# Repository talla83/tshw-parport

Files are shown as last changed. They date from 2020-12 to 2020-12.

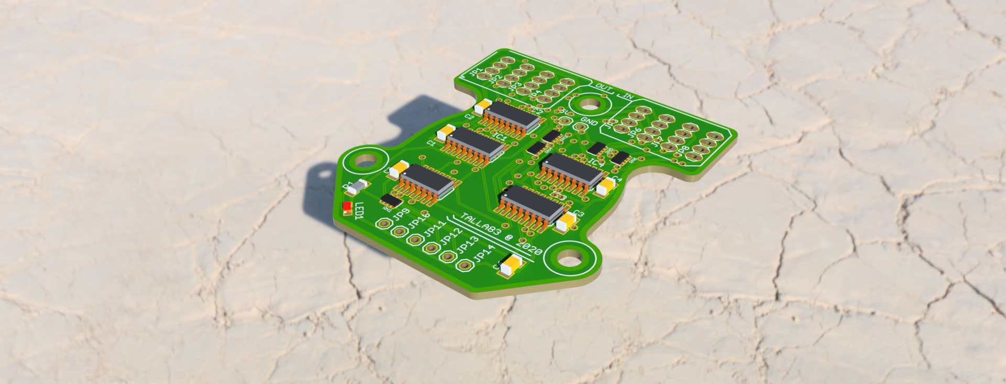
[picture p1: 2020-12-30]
Eagle/DEV_001 v9.png

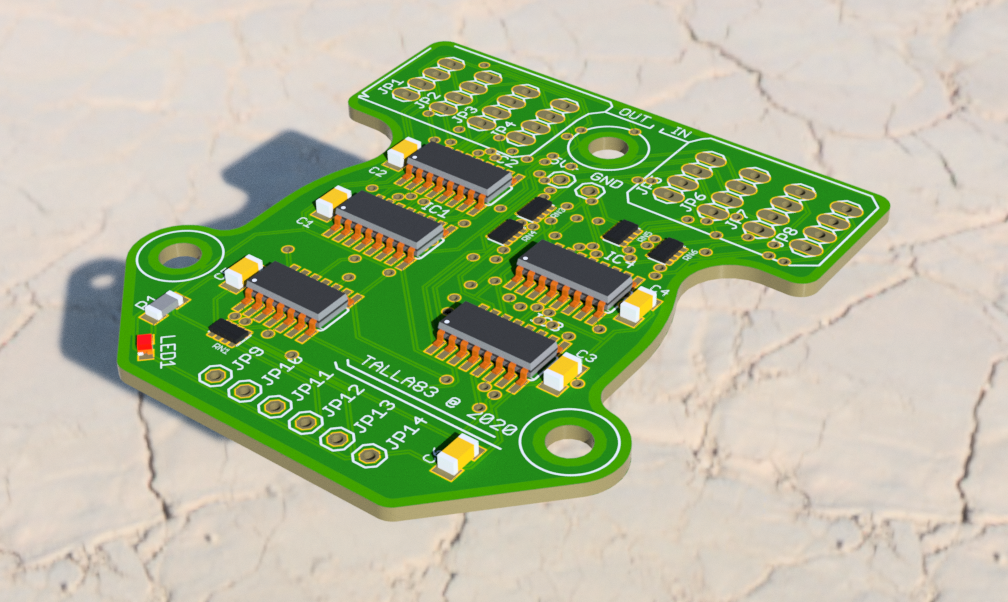
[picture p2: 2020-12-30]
Eagle/Unbenannt.PNG

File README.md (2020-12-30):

lsrio16 für Tom simple handwheel -
Eine kleine Erweiterungsplatine mit universellen IOs.

16 x digital output 16 x digital input 

Schnittstelle = Parallel Port oder andere mit GPIO

Der Encoder muss direkt an den ParPort angeschlossen.

http://wiki.linuxcnc.org/cgi-bin/wiki.pl?Shift_Register_Port_Expander

https://www.thingiverse.com/thing:3684937

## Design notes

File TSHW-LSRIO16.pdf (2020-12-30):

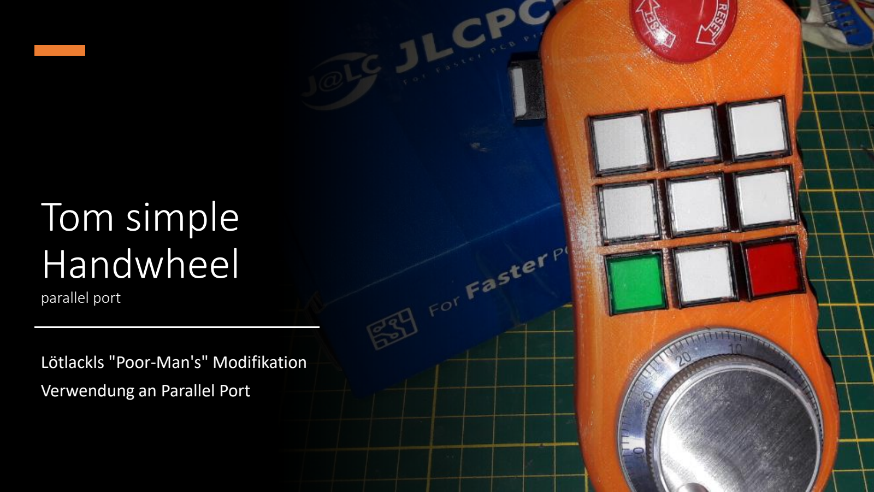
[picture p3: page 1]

# Tom simple Handwheel

parallel port

### Lötlackls "Poor-Man's" Modifikation Verwendung an Parallel Port

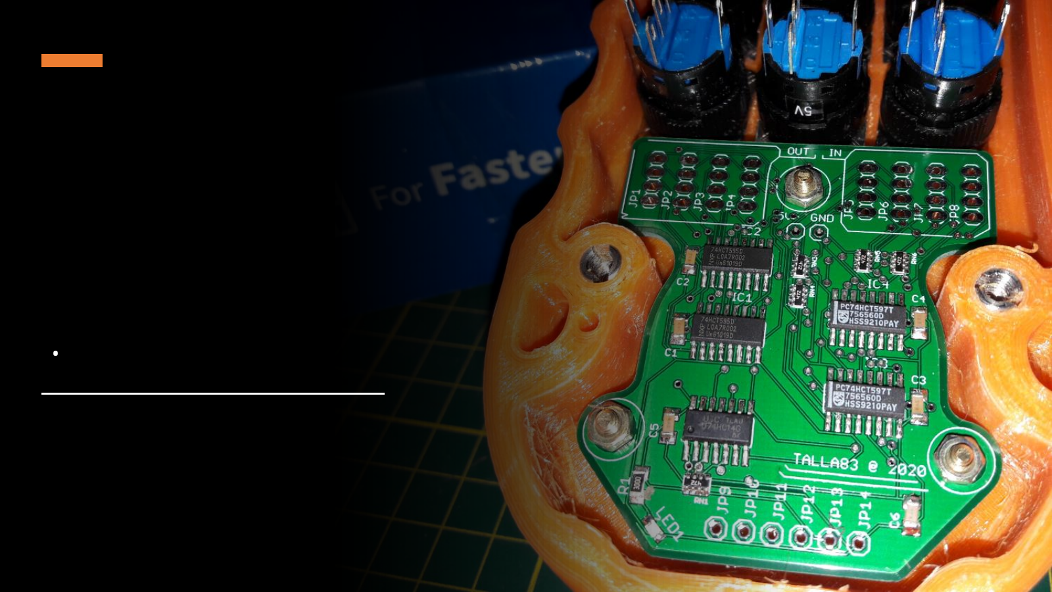
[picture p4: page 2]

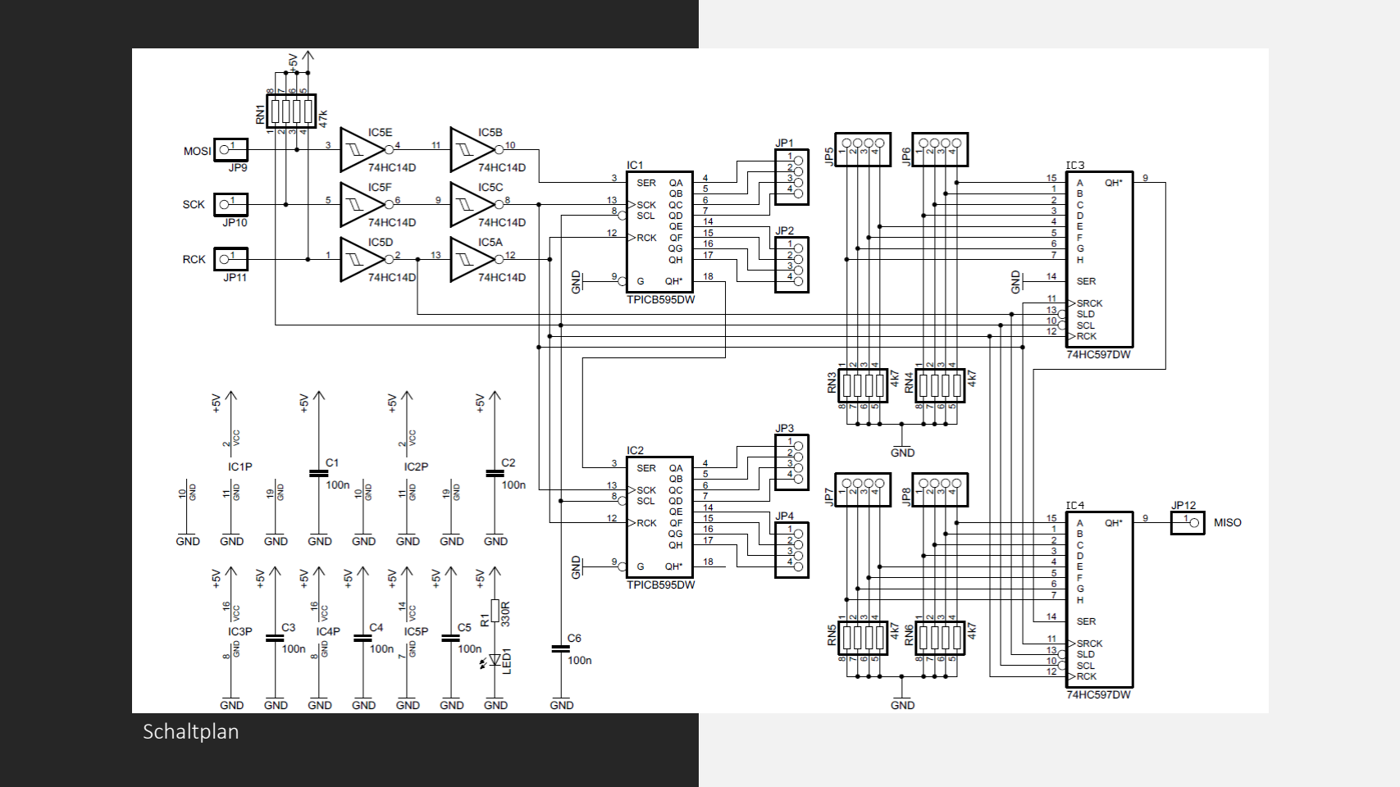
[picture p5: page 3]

Schaltplan

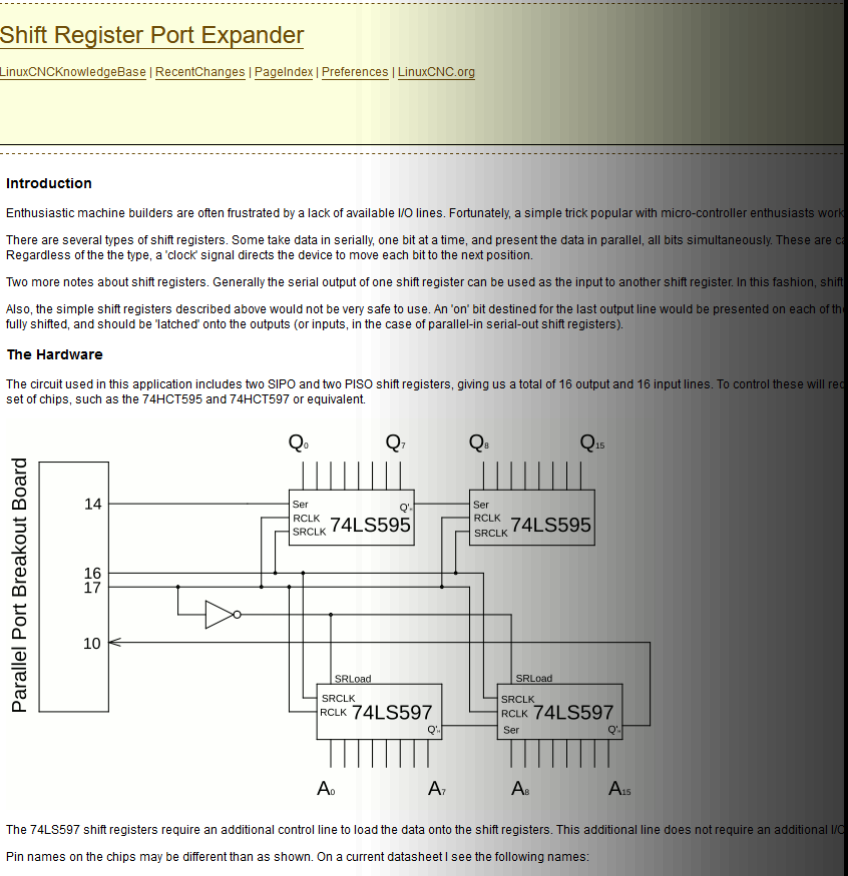
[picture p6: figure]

Die Funktionsbeschreibung gibt es hier…

http://wiki.linuxcnc.org/cgi-bin/wiki.pl?Shift_Register_Port_Expander

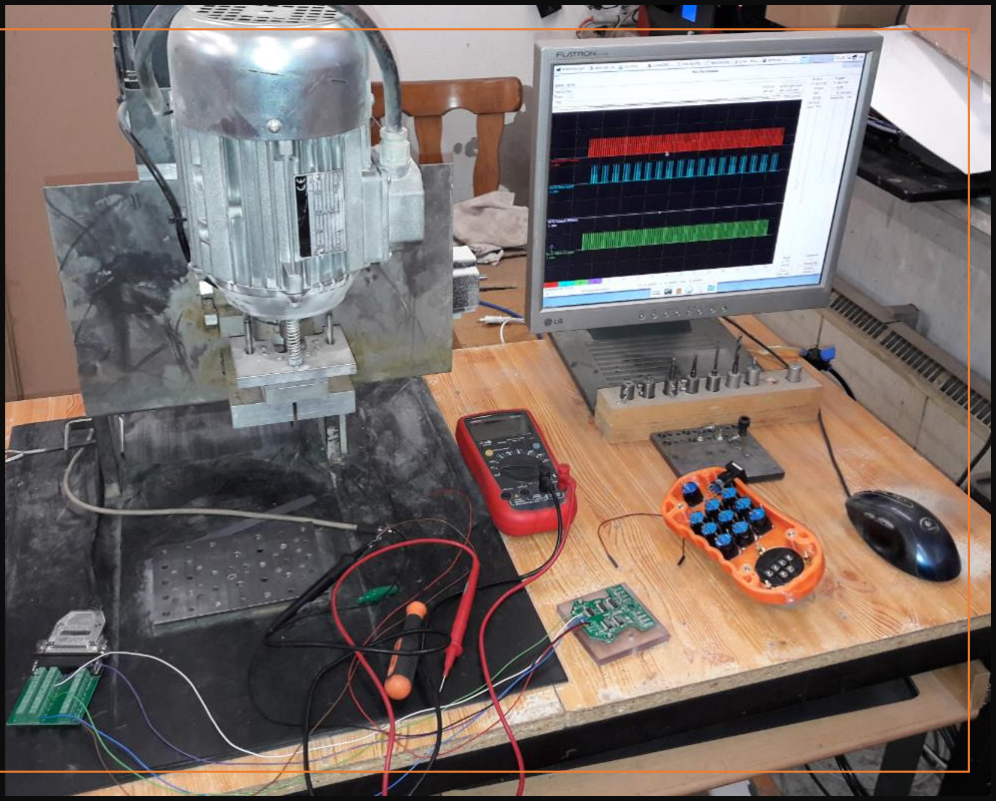
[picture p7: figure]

# Testaufbau

# Übersicht Verdrahtung

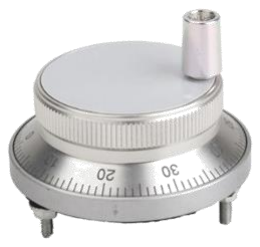
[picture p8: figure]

16 Eingänge
16 Ausgänge

Parallel Port

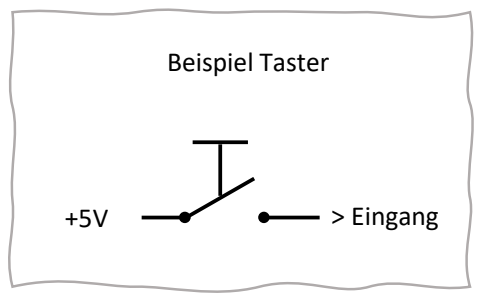
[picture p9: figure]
> Eingang; Beispiel Taster
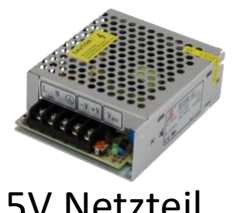
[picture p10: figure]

5V Netzteil

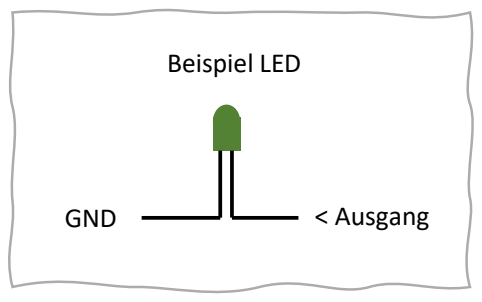
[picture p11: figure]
GND; < Ausgang; Beispiel LED

Platine | Handrad Encoder

+5V

GND

A
B

Es werden hier insgesamt 6 PINS benötigt. 3 Eingänge
3 Ausgänge

# .. lsrio16

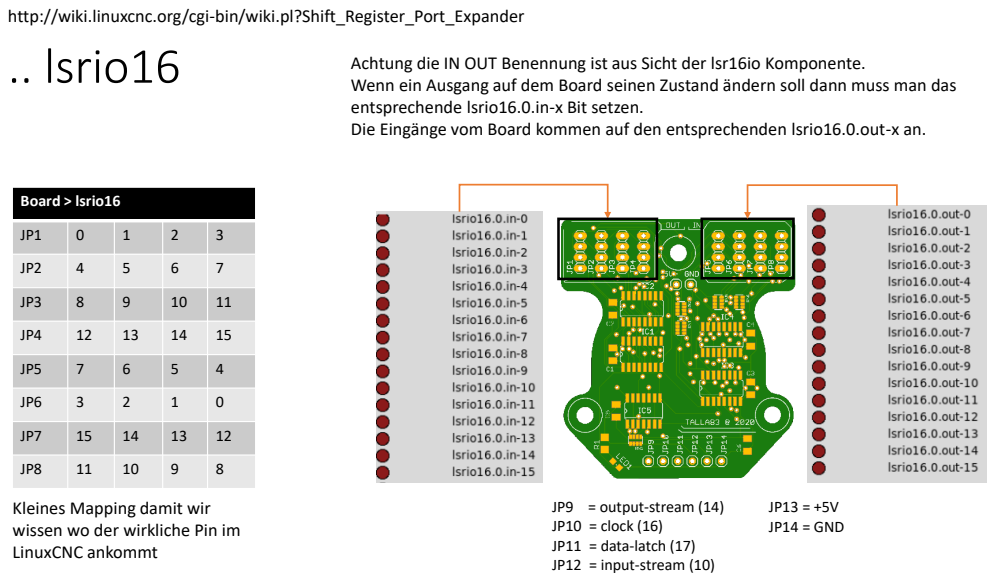
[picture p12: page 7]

http://wiki.linuxcnc.org/cgi-bin/wiki.pl?Shift_Register_Port_Expander

Achtung die IN OUT Benennung ist aus Sicht der lsr16io Komponente.
Wenn ein Ausgang auf dem Board seinen Zustand ändern soll dann muss man das
entsprechende lsrio16.0.in-x Bit setzen.
Die Eingänge vom Board kommen auf den entsprechenden lsrio16.0.out-x an.

Kleines Mapping damit wir
wissen wo der wirkliche Pin im
LinuxCNC ankommt

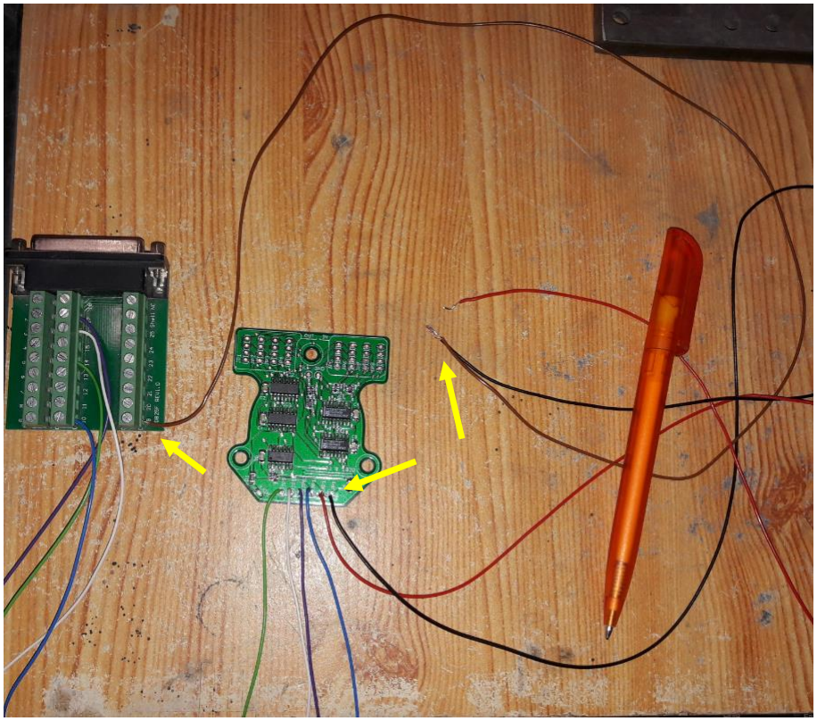
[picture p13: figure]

# .. lsrio16

GND der Spannungsversorgung muss auch mit dem GND des
Parallel Port verbunden werden!

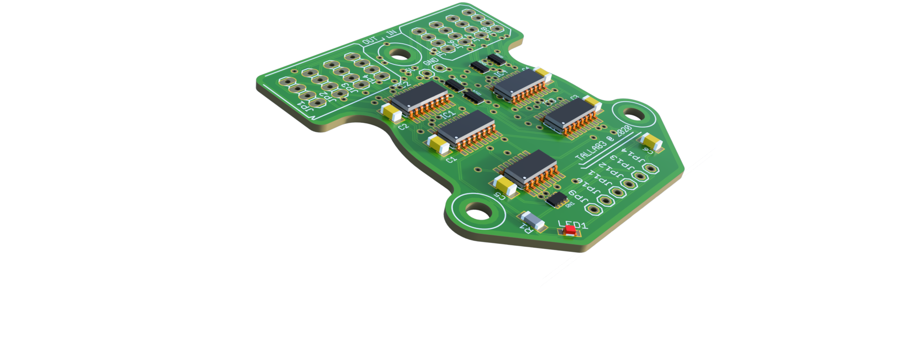
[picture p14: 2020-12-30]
Eagle/DEV_001_2020-Dec-01_08-29-42PM-000_CustomizedView25017234391.png

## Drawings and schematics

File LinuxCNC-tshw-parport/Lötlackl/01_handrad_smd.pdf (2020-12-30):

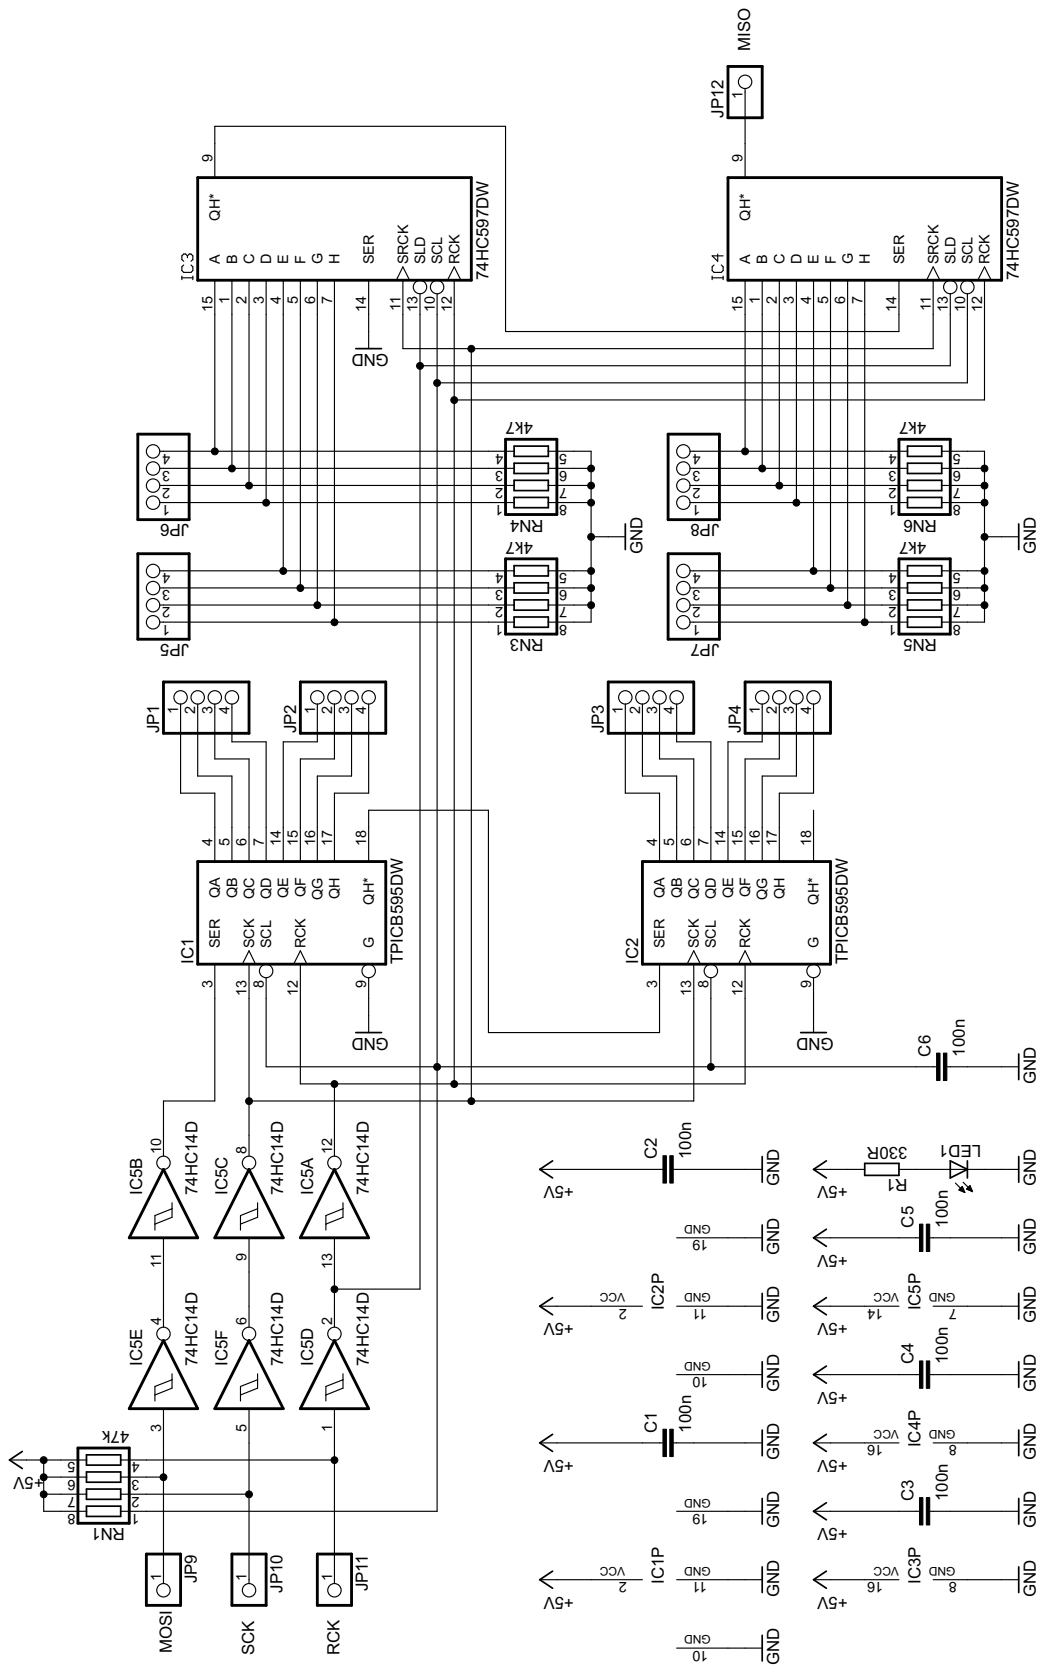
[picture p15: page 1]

GND GND

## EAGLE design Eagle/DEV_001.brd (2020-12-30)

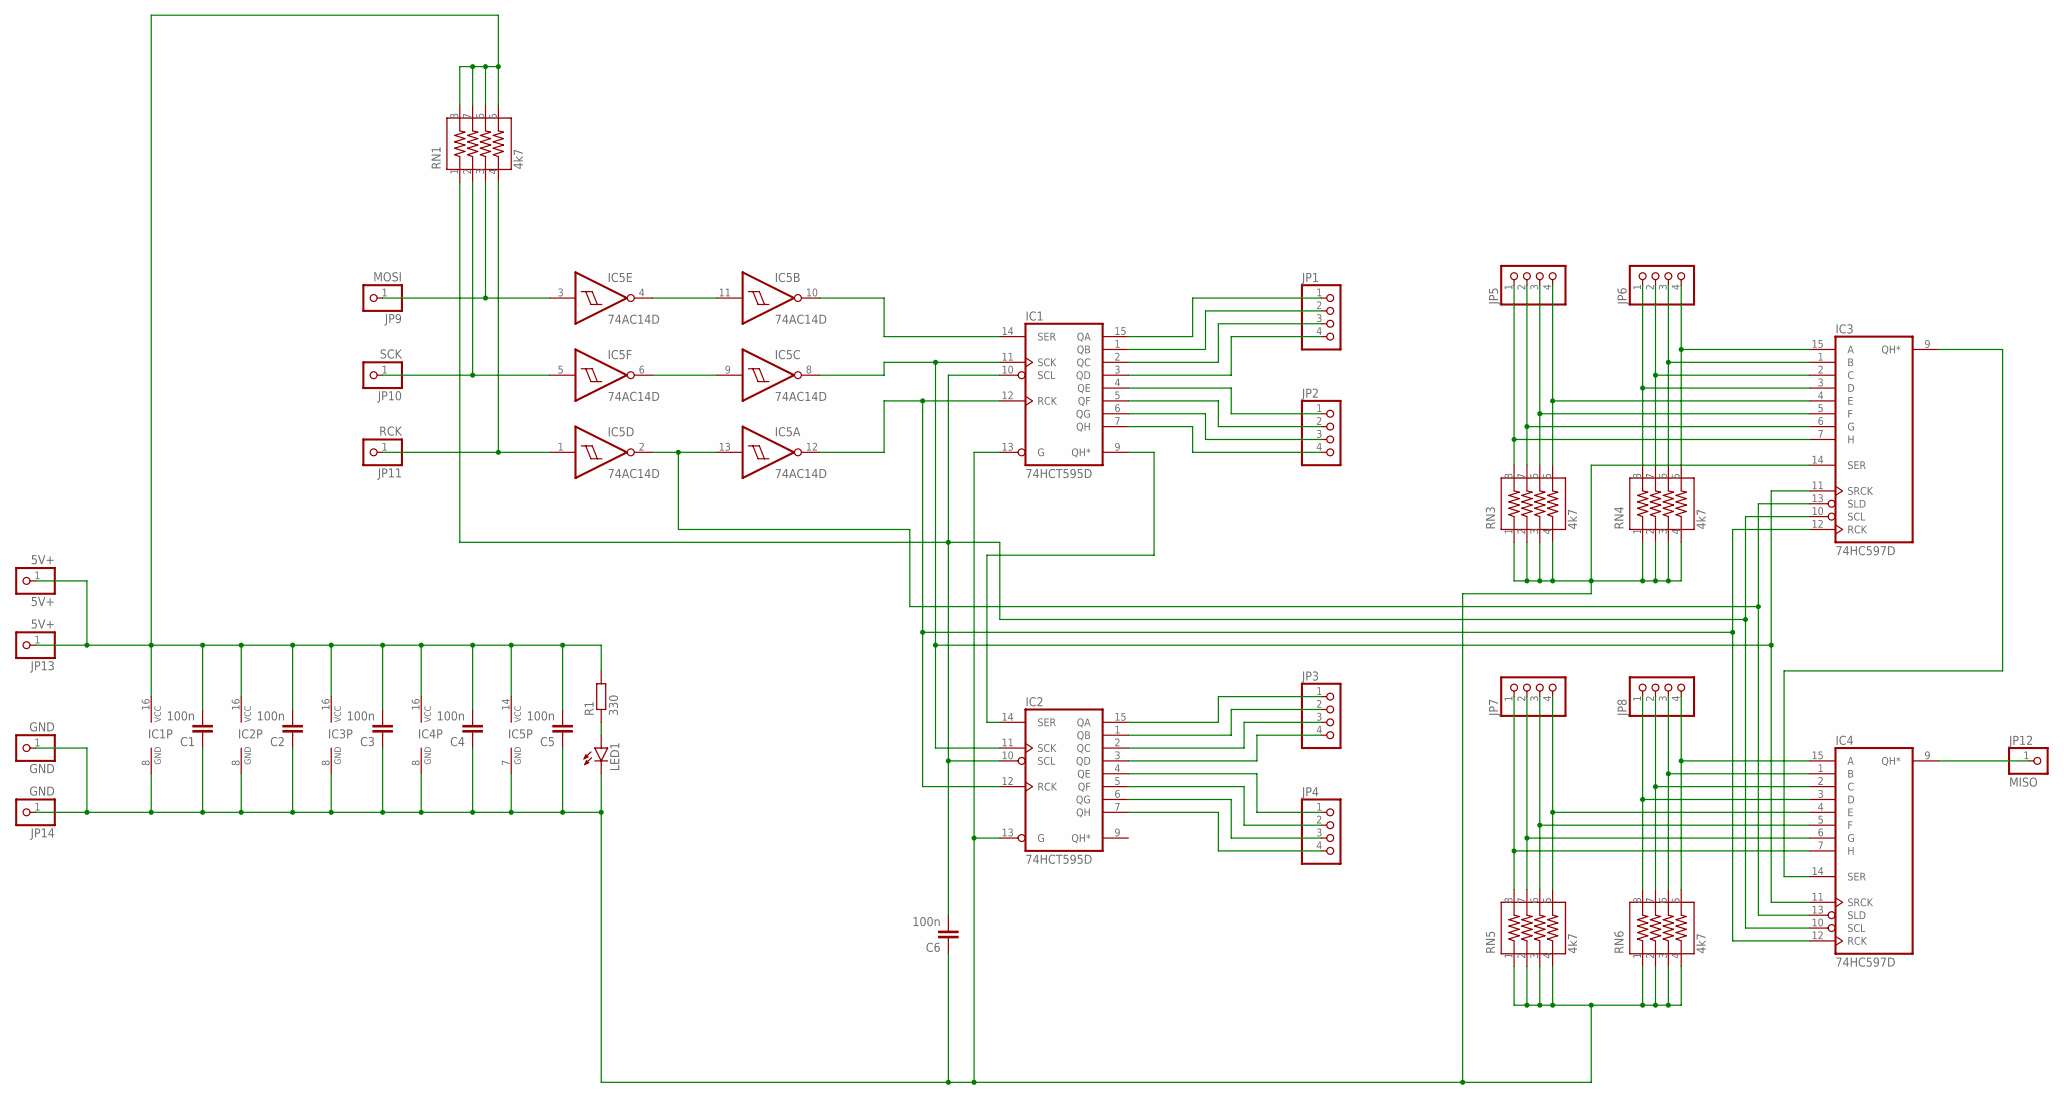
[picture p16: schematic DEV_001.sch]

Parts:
5V+: 5V+; 1X01
C1, C2, C3, C4, C5, C6: 100n; C1206K
GND: GND; 1X01
IC1, IC2: 74HCT595D; SO16
IC3, IC4: 74HC597D; SO16
IC5: 74AC14D; SO14
JP1, JP2, JP3, JP4, JP5, JP6, JP7, JP8: PINHD-1X4; 1X04
JP9: MOSI; 1X01
JP10: SCK; 1X01
JP11: RCK; 1X01
JP12: MISO; 1X01
JP13: 5V+; 1X01
JP14: GND; 1X01
LED1: LEDCHIPLED_0805; CHIPLED_0805
R1: 330; R1206
RN1, RN3, RN4, RN5, RN6: 4k7; 742C083103JP

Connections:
unnamed: IC5.4 (O), IC5.11 (I)
unnamed: IC5.6 (O), IC5.9 (I)
unnamed: IC5.3 (I), JP9.1, RN1.3
unnamed: IC5.5 (I), JP10.1, RN1.2
unnamed: IC5.1 (I), JP11.1, RN1.4
unnamed: 5V+.1, C1.2, C2.2, C3.2, C4.2, C5.2, IC1.16 (VCC), IC2.16 (VCC), IC3.16 (VCC), IC4.16 (VCC), IC5.14 (VCC), JP13.1, R1.2, RN1.5, RN1.6, RN1.7, RN1.8
unnamed: IC1.14 (SER), IC5.10 (O)
unnamed: C1.1, C2.1, C3.1, C4.1, C5.1, C6.1, GND.1, IC1.8 (GND), IC1.13 (G), IC2.8 (GND), IC2.13 (G), IC3.8 (GND), IC3.14 (SER), IC4.8 (GND), IC5.7 (GND), JP14.1, LED1.C, RN3.1, RN3.2, RN3.3, RN3.4, RN4.1, RN4.2, RN4.3, RN4.4, RN5.1, RN5.2, RN5.3, RN5.4, RN6.1, RN6.2, RN6.3, RN6.4
unnamed: IC1.15 (QA), JP1.1
unnamed: IC1.1 (QB), JP1.2
unnamed: IC1.2 (QC), JP1.3
unnamed: IC1.3 (QD), JP1.4
unnamed: IC1.4 (QE), JP2.1
unnamed: IC1.5 (QF), JP2.2
unnamed: IC1.6 (QG), JP2.3
unnamed: IC1.7 (QH), JP2.4
unnamed: IC1.9 (QH*), IC2.14 (SER)
unnamed: IC2.15 (QA), JP3.1
unnamed: IC2.1 (QB), JP3.2
unnamed: IC2.2 (QC), JP3.3
unnamed: IC2.3 (QD), JP3.4
unnamed: IC2.4 (QE), JP4.1
unnamed: IC2.5 (QF), JP4.2
unnamed: IC2.6 (QG), JP4.3
unnamed: IC2.7 (QH), JP4.4
unnamed: IC3.9 (QH*), IC4.14 (SER)
unnamed: IC4.9 (QH*), JP12.1
unnamed: IC3.7 (H), JP5.1, RN3.8
unnamed: IC3.6 (G), JP5.2, RN3.7
unnamed: IC3.5 (F), JP5.3, RN3.6
unnamed: IC3.4 (E), JP5.4, RN3.5
unnamed: IC3.3 (D), JP6.1, RN4.8
unnamed: IC3.2 (C), JP6.2, RN4.7
unnamed: IC3.1 (B), JP6.3, RN4.6
unnamed: IC3.15 (A), JP6.4, RN4.5
unnamed: IC1.11 (SCK), IC2.11 (SCK), IC3.11 (SRCK), IC4.11 (SRCK), IC5.8 (O)
unnamed: IC3.13 (SLD), IC4.13 (SLD), IC5.2 (O), IC5.13 (I)
unnamed: IC1.12 (RCK), IC2.12 (RCK), IC3.12 (RCK), IC4.12 (RCK), IC5.12 (O)
unnamed: IC4.7 (H), JP7.1, RN5.8
unnamed: IC4.6 (G), JP7.2, RN5.7
unnamed: IC4.5 (F), JP7.3, RN5.6
unnamed: IC4.4 (E), JP7.4, RN5.5
unnamed: IC4.3 (D), JP8.1, RN6.8
unnamed: IC4.2 (C), JP8.2, RN6.7
unnamed: IC4.1 (B), JP8.3, RN6.6
unnamed: IC4.15 (A), JP8.4, RN6.5
unnamed: LED1.A, R1.1
unnamed: C6.2, IC1.10 (SCL), IC2.10 (SCL), IC3.10 (SCL), IC4.10 (SCL), RN1.1

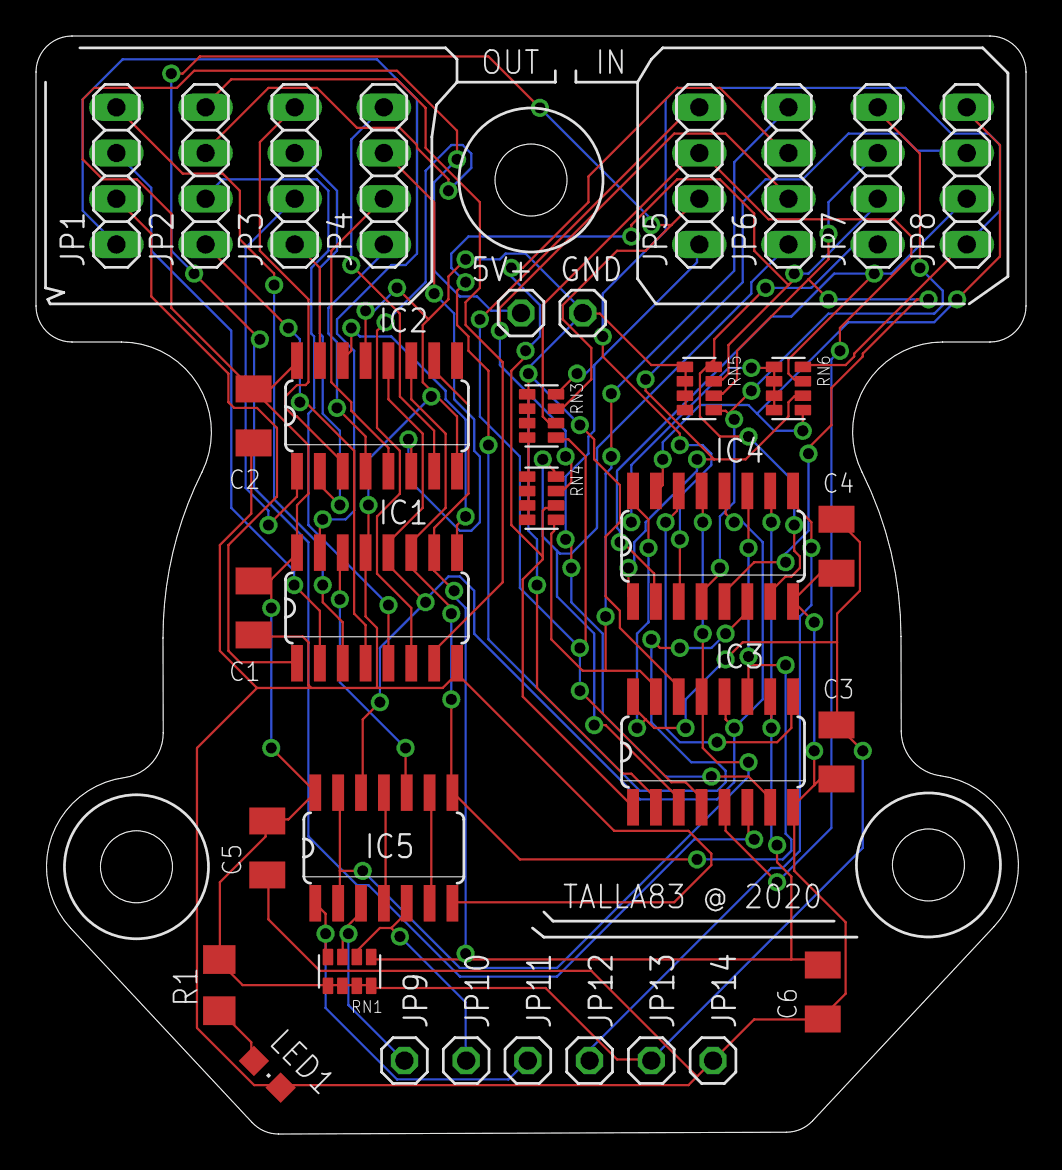
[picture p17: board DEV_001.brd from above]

Board: 2 copper layers, 55.0 x 61.0 mm, 34 parts (0 on the bottom side), 48 nets.

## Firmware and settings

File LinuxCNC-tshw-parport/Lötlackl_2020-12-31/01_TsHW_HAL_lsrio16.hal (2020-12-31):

###################################################################
# TsHW Talla simple Hand Wheel  LinuxCNC Version 2.8
###################################################################
# ilowpass und and2   
#
# Wenn diese schon in einer anderen HAL geladen bzw. verwendet werden,
# dann muss dies in der Struktur beachtet werden.
# Denn doppeltes laden von Komponenten ist nicht möglich.
# Es müssen die loadrt Befehle auskommentiert werden und
# die loadrt Befehle in den anderen HAL Dateien mit diesen Namen 
# ergänzt werden.
# addf kann hier bleiben :-)
# 
# Damit der Zero der Achsen geht müssen in der INI die MDI Commands 
# angelegt werden 
#
#	[HALUI]
#	MDI_COMMAND = G10 L20 P1 X0
#	MDI_COMMAND = G10 L20 P1 Y0
#	MDI_COMMAND = G10 L20 P1 Z0
#
#
#
# Mit setp shw.enc-smooth.gain  kann die Beschleunigung eingestellt werden.
# und mit setp shw.enc-smooth.scale die Übersetzung
#
###################################################################

###################################################################
# Lötlackls "Poor-Man's" Modifikation
# unter Verwendung von Schieberegistern
# und eines Parallelports anstelle von diversen MESA-Karten.
# Unter diesen Umständen gibt es freilich keinen Analogeingang.
#
# Im Gegensatz zum Wiki-Eintrag betreffend "lsrio16"
# heißt der Befehl zum kompilieren und installieren
# des Software-Moduls "lsrio16.comp"
# anstatt    "sudo comp --install lsrio16.comp"
# inzwischen "sudo halcompile --install lsrio16.comp"
#
# Talla83 - LinuxCNC 2.8 Ergänzung bezüglich der Tools zum compile
# Wenn halcompile nicht installiert ist dann benötigen wir noch folgendes Paket
# sudo apt-get install linuxcnc-uspace-dev
# sudo spt-get install make
# sudo halcompile --install lsrio16.comp
#
# folgend das Ergebnis 
#
# cnc@cnc:~$ sudo halcompile --install lsrio16.comp
# Compiling realtime lsrio16.c
# Linking lsrio16.so
# cp lsrio16.so /usr/lib/linuxcnc/modules/
# 
# lsrio16 ist installiert und kann verwendet werden
#
# Das Handrad wird direkt an den Parallelport angeschlossen.
###################################################################

####################
##      TsHW      ##
####################

loadrt lsrio16 count=1
addf lsrio16.0 base-thread

net lsrio-input-stream lsrio16.0.ser-in <= parport.1.pin-10-in
net lsrio-output-stream lsrio16.0.ser-out => parport.1.pin-14-out
net lsrio-clock-output lsrio16.0.clk => parport.1.pin-16-out
net lsrio-data-latch lsrio16.0.latch => parport.1.pin-09-out

loadrt debounce cfg=2,10
addf debounce.0 base-thread
addf debounce.1 base-thread
setp debounce.1.delay 50 

loadrt encoder names=shw.encoder
addf encoder.capture-position servo-thread
addf encoder.update-counters base-thread
setp shw.encoder.position-scale 4

loadrt conv_float_s32 names=shw.conv
addf shw.conv servo-thread

net conv shw.conv.in <= shw.encoder.position

net rawquada      debounce.0.0.in  <= parport.1.pin-11-in
net rawquadb      debounce.0.1.in  <= parport.1.pin-12-in
net cleanquada    debounce.0.0.out => shw.encoder.phase-A
net cleanquadb    debounce.0.1.out => shw.encoder.phase-B

# Inputs der Taster
net raw-key-x     lsrio16.0.out-0  => debounce.1.0.in
net raw-key-y     lsrio16.0.out-1  => debounce.1.1.in
net raw-key-z     lsrio16.0.out-2  => debounce.1.2.in
net raw-key-0001  lsrio16.0.out-3  => debounce.1.3.in
net raw-key-001   lsrio16.0.out-4  => debounce.1.4.in
net raw-key-01    lsrio16.0.out-5  => debounce.1.5.in
net raw-key-stop  lsrio16.0.out-6  => debounce.1.6.in
net raw-key-zero  lsrio16.0.out-7  => debounce.1.7.in
net raw-key-run   lsrio16.0.out-8  => debounce.1.8.in
net raw-key-ena   lsrio16.0.out-9  => debounce.1.9.in

# Outputs für die LEDs der Taster
net key-x      => lsrio16.0.in-0
net key-y      => lsrio16.0.in-1
net key-z      => lsrio16.0.in-2
net key-0001   => lsrio16.0.in-3
net key-001    => lsrio16.0.in-4
net key-01     => lsrio16.0.in-5
# net led-run-pause shw.run-pause.out => lsrio16.0.in-6
net key-zero   => lsrio16.0.in-7
net led-stop   => lsrio16.0.in-8
net key-ena    => lsrio16.0.in-9

loadrt lut5 names=shw.lock-xyz,shw.lock-step,shw.nor-xyz,shw.nor-step,shw.nor-estop,shw.run-pause
addf shw.lock-xyz   servo-thread
addf shw.lock-step  servo-thread
addf shw.nor-xyz    servo-thread
addf shw.nor-step   servo-thread
addf shw.nor-estop  servo-thread
addf shw.run-pause  servo-thread

setp shw.lock-xyz.function 0x16
setp shw.lock-step.function 0x16
setp shw.nor-xyz.function 0x01
setp shw.nor-step.function 0x01
setp shw.nor-estop.function 0x01
setp shw.run-pause.function 0x62

loadrt ilowpass names=shw.enc-smooth
addf shw.enc-smooth servo-thread

setp shw.enc-smooth.scale 1
setp shw.enc-smooth.gain 0.025
setp joint.0.jog-vel-mode 1
setp axis.x.jog-vel-mode 1

setp joint.1.jog-vel-mode 1
setp axis.y.jog-vel-mode 1

setp joint.2.jog-vel-mode 1
setp axis.z.jog-vel-mode 1

loadrt and2 names=shw.ena-x,shw.ena-y,shw.ena-z,shw.zero-x,shw.zero-y,shw.zero-z

addf shw.ena-x servo-thread
addf shw.ena-y servo-thread
addf shw.ena-z servo-thread

addf shw.zero-x servo-thread
addf shw.zero-y servo-thread
addf shw.zero-z servo-thread

loadrt mux8 names=shw.step-choice
addf shw.step-choice servo-thread

net key-0001 => shw.step-choice.sel0
net key-001  => shw.step-choice.sel1
net key-01   => shw.step-choice.sel2

setp shw.step-choice.in1 0.001
setp shw.step-choice.in2 0.01
setp shw.step-choice.in4 0.1

net step-choice <= shw.step-choice.out
net step-choice => joint.0.jog-scale axis.x.jog-scale
net step-choice => joint.1.jog-scale axis.y.jog-scale
net step-choice => joint.2.jog-scale axis.z.jog-scale

############################################
# prinzipieller Aufbau der Tastenlogik     #
#                           ______         #
#                          |  FF  |        #
#               oneshot----| S  Q |-- out1 #
#                          |      |        #
# key1---------------------| D    |        #
#                          |      |        #
#                          |      |        #
#                        .-| CLK  |        #
#                        | |      |        #
#                        | | R    |        #
#                        | |______|        #
#                        |                 #
#                        |                 #
#                        |  ______         #
#                        | |  FF  |        #
#                        | | S  Q |-- out2 #
#                        | |      |        #
# key2-------------------+-| D    |        #
#                        | |      |        #
#                        | |      |        #
#                        x-| CLK  |        #
#                        | |      |        #
#               oneshot--+-| R    |        #
#                        | |______|        #
#                        |                 #
#                        |                 #
#                        |  ______         #
#                        | |  FF  |        #
#                        | | S  Q |-- out3 #
#                        | |      |        #
# key3-------------------+-| D    |        #
#                        | |      |        #
#                        | |      |        #
#                        x-| CLK  |        #
#         ___            | |      |        #
# key1---|xor|  oneshot--+-| R    |        #
#        |   |      ___  | |______|        #
# key2---|lut|-----|  &| |                 #
#        |1/2|     |   | |                 #
# key3---|___|     |lut| |  ______         #
#                  |2/2| | |  FF  |        #
#        key-ena---o   |-x-| S  Q |--.     #
#                  |   |   |      |  |     #
#                  |   |   |      |  |     #
#                  |   |   |      |  |     #
#         ___   .--o___|   |      |  |     #
# key1---|  1|  |          |      |  |     #
#        |   |  |          |      |  |     #
# key2---|   o--+----------| R    |  |     #
#        |   |  |          |______|  |     #
# key3---|___|  |____________________|     #
#                   net lock-***           #
############################################

loadrt flipflop names=shw.ff-x,shw.ff-y,shw.ff-z,shw.ff-0001,shw.ff-001,shw.ff-01,shw.ff-xyz-lock,shw.ff-step-lock

addf shw.ff-x         servo-thread
addf shw.ff-y         servo-thread
addf shw.ff-z         servo-thread
addf shw.ff-0001      servo-thread
addf shw.ff-001       servo-thread
addf shw.ff-01        servo-thread
addf shw.ff-xyz-lock  servo-thread
addf shw.ff-step-lock servo-thread

net ff-data-x   <= debounce.1.0.out
net ff-data-y   <= debounce.1.1.out
net ff-data-z   <= debounce.1.2.out

net ff-data-x   => shw.lock-xyz.in-0
net ff-data-y   => shw.lock-xyz.in-1
net ff-data-z   => shw.lock-xyz.in-2

net ff-data-x   => shw.nor-xyz.in-0
net ff-data-y   => shw.nor-xyz.in-1
net ff-data-z   => shw.nor-xyz.in-2

net lock-xyz    <= shw.ff-xyz-lock.out
net lock-xyz    => shw.lock-xyz.in-3
net key-ena     => shw.lock-xyz.in-4

net release-xyz <= shw.nor-xyz.out
net release-xyz => shw.ff-xyz-lock.reset
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

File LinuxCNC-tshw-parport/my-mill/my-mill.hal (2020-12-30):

# Generated by stepconf 1.1 at Sun Dec 27 16:18:48 2020
# Änderungen an dieser Datei werden beim nächsten
# overwritten when you run stepconf again
loadrt [KINS]KINEMATICS
loadrt [EMCMOT]EMCMOT base_period_nsec=[EMCMOT]BASE_PERIOD servo_period_nsec=[EMCMOT]SERVO_PERIOD num_joints=[KINS]JOINTS
loadrt hal_parport cfg="0 out 1 out"
setp parport.0.reset-time 5000
loadrt stepgen step_type=0,0,0
loadrt pwmgen output_type=1

addf parport.0.read base-thread
addf parport.1.read base-thread
addf stepgen.make-pulses base-thread
addf pwmgen.make-pulses base-thread
addf parport.0.write base-thread
addf parport.0.reset base-thread
addf parport.1.write base-thread

addf stepgen.capture-position servo-thread
addf motion-command-handler servo-thread
addf motion-controller servo-thread
addf stepgen.update-freq servo-thread
addf pwmgen.update servo-thread

net spindle-cmd-rpm => pwmgen.0.value
net spindle-on <= spindle.0.on => pwmgen.0.enable
net spindle-pwm <= pwmgen.0.pwm
setp pwmgen.0.pwm-freq 1000.0
setp pwmgen.0.scale 3500.0
setp pwmgen.0.offset 0.0
setp pwmgen.0.dither-pwm true
net spindle-cmd-rpm     <= spindle.0.speed-out
net spindle-cmd-rpm-abs <= spindle.0.speed-out-abs
net spindle-cmd-rps     <= spindle.0.speed-out-rps
net spindle-cmd-rps-abs <= spindle.0.speed-out-rps-abs
net spindle-at-speed    => spindle.0.at-speed
net spindle-cw <= spindle.0.forward

net estop-out       => parport.0.pin-01-out
setp parport.0.pin-02-out-invert 1
net xstep           => parport.0.pin-02-out
setp parport.0.pin-02-out-reset 1
net xdir            => parport.0.pin-03-out
setp parport.0.pin-04-out-invert 1
net ystep           => parport.0.pin-04-out
setp parport.0.pin-04-out-reset 1
net ydir            => parport.0.pin-05-out
setp parport.0.pin-06-out-invert 1
net zstep           => parport.0.pin-06-out
setp parport.0.pin-06-out-reset 1
net zdir            => parport.0.pin-07-out
setp parport.0.pin-08-out-invert 1
net xenable         => parport.0.pin-08-out
net spindle-on      => parport.0.pin-09-out
setp parport.0.pin-14-out-invert 1
net spindle-cw      => parport.0.pin-14-out
net spindle-pwm     => parport.0.pin-16-out


net home-x          <= parport.0.pin-10-in-not
net home-y          <= parport.0.pin-11-in-not
net home-z          <= parport.0.pin-12-in-not



setp stepgen.0.position-scale [JOINT_0]SCALE
setp stepgen.0.steplen 1
setp stepgen.0.stepspace 0
setp stepgen.0.dirhold 30000
setp stepgen.0.dirsetup 30000
setp stepgen.0.maxaccel [JOINT_0]STEPGEN_MAXACCEL
net xpos-cmd joint.0.motor-pos-cmd => stepgen.0.position-cmd
net xpos-fb stepgen.0.position-fb => joint.0.motor-pos-fb
net xstep <= stepgen.0.step
net xdir <= stepgen.0.dir
net xenable joint.0.amp-enable-out => stepgen.0.enable
net home-x => joint.0.home-sw-in

setp stepgen.1.position-scale [JOINT_1]SCALE
setp stepgen.1.steplen 1
setp stepgen.1.stepspace 0
setp stepgen.1.dirhold 30000
setp stepgen.1.dirsetup 30000
setp stepgen.1.maxaccel [JOINT_1]STEPGEN_MAXACCEL
net ypos-cmd joint.1.motor-pos-cmd => stepgen.1.position-cmd
net ypos-fb stepgen.1.position-fb => joint.1.motor-pos-fb
net ystep <= stepgen.1.step
net ydir <= stepgen.1.dir
net yenable joint.1.amp-enable-out => stepgen.1.enable
net home-y => joint.1.home-sw-in

setp stepgen.2.position-scale [JOINT_2]SCALE
setp stepgen.2.steplen 1
setp stepgen.2.stepspace 0
setp stepgen.2.dirhold 30000
setp stepgen.2.dirsetup 30000
setp stepgen.2.maxaccel [JOINT_2]STEPGEN_MAXACCEL
net zpos-cmd joint.2.motor-pos-cmd => stepgen.2.position-cmd
net zpos-fb stepgen.2.position-fb => joint.2.motor-pos-fb
net zstep <= stepgen.2.step
net zdir <= stepgen.2.dir
net zenable joint.2.amp-enable-out => stepgen.2.enable
net home-z => joint.2.home-sw-in

#net estop-out <= iocontrol.0.user-enable-out

net estop-out <= parport.1.pin-13-in-not
net estop-out => iocontrol.0.emc-enable-in

loadusr -W hal_manualtoolchange
net tool-change iocontrol.0.tool-change => hal_manualtoolchange.change
net tool-changed iocontrol.0.tool-changed <= hal_manualtoolchange.changed
net tool-number iocontrol.0.tool-prep-number => hal_manualtoolchange.number
net tool-prepare-loopback iocontrol.0.tool-prepare => iocontrol.0.tool-prepared
